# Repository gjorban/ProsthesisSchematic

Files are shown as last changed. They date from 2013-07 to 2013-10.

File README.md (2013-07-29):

Copyright (C) 2012 Gerald Orban

Permission is hereby granted, free of charge, to any person obtaining
a copy of this software and associated documentation files (the
"Software"), to deal in the Software without restriction, including
without limitation the rights to use, copy, modify, merge, publish,
distribute, sublicense, and/or sell copies of the Software, and to
permit persons to whom the Software is furnished to do so, subject to
the following conditions:

The above copyright notice and this permission notice shall be
included in all copies or substantial portions of the Software.

THE SOFTWARE IS PROVIDED "AS IS", WITHOUT WARRANTY OF ANY KIND,
EXPRESS OR IMPLIED, INCLUDING BUT NOT LIMITED TO THE WARRANTIES OF
MERCHANTABILITY, FITNESS FOR A PARTICULAR PURPOSE AND
NONINFRINGEMENT. IN NO EVENT SHALL GERALD ORBAN BE LIABLE FOR ANY
CLAIM, DAMAGES OR OTHER LIABILITY, WHETHER IN AN ACTION OF CONTRACT,
TORT OR OTHERWISE, ARISING FROM, OUT OF OR IN CONNECTION WITH THE
SOFTWARE OR THE USE OR OTHER DEALINGS IN THE SOFTWARE.

Except as contained in this notice, the name of Gerald Orban shall
not be used in advertising or otherwise to promote the sale, use or
other dealings in this Software without prior written authorization
from Gerald Orban.

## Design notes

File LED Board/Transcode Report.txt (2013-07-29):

   ---- Transcoding 'C:\Users\Gbot\Desktop\eatART LED Board\i2clight manual route.GBS' ----   Fri Jun 21 15:23:17 2013

D10   --> D100
D11   --> D101
D12   --> D102
D13   --> D103
D14   --> D104
D15   --> D105
D16   --> D106
D17   --> D107
-----------------------------------------------------------------

   ---- Transcoding 'C:\Users\Gbot\Desktop\eatART LED Board\i2clight manual route.GTL' ----   Fri Jun 21 15:23:17 2013

D10   --> D108
D11   --> D109
D12   --> D110
D13   --> D111
D14   --> D112
D15   --> D113
D16   --> D114
D17   --> D115
D18   --> D116
D19   --> D117
D20   --> D118
-----------------------------------------------------------------

   ---- Transcoding 'C:\Users\Gbot\Desktop\eatART LED Board\i2clight manual route.GTO' ----   Fri Jun 21 15:23:17 2013

D10   --> D119
D11   --> D120
D12   --> D121
D13   --> D122
D14   --> D123
D15   --> D124
D16   --> D125
D17   --> D126
D18   --> D127
D19   --> D128
D20   --> D129
D21   --> D130
D22   --> D131
D23   --> D132
D24   --> D133
D25   --> D134
D26   --> D135
D100  --> D136
D101  --> D137
D102  --> D138
D103  --> D139
-----------------------------------------------------------------

   ---- Transcoding 'C:\Users\Gbot\Desktop\eatART LED Board\i2clight manual route.GTS' ----   Fri Jun 21 15:23:17 2013

D10   --> D140
D11   --> D141
D12   --> D142
D13   --> D143
D14   --> D144
D15   --> D145
D16   --> D146
D17   --> D147
D18   --> D148
D19   --> D149
D20   --> D150
D21   --> D151
-----------------------------------------------------------------

   ---- Transcoding 'C:\Users\Gbot\Desktop\eatART LED Board\i2clight manual route.GBS' ----   Fri Jun 21 15:51:15 2013

D10   --> D100
D11   --> D101
D12   --> D102
D13   --> D103
D14   --> D104
D15   --> D105
D16   --> D106
D17   --> D107
-----------------------------------------------------------------

   ---- Transcoding 'C:\Users\Gbot\Desktop\eatART LED Board\i2clight manual route.GTL' ----   Fri Jun 21 15:51:15 2013

D10   --> D108
D11   --> D109
D12   --> D110
D13   --> D111
D14   --> D112
D15   --> D113
D16   --> D114
D17   --> D115
D18   --> D116
D19   --> D117
D20   --> D118
-----------------------------------------------------------------

   ---- Transcoding 'C:\Users\Gbot\Desktop\eatART LED Board\i2clight manual route.GTO' ----   Fri Jun 21 15:51:15 2013

D10   --> D119
D11   --> D120
D12   --> D121
D13   --> D122
D14   --> D123
D15   --> D124
D16   --> D125
D17   --> D126
D18   --> D127
D19   --> D128
D20   --> D129
D21   --> D130
D22   --> D131
D23   --> D132
D24   --> D133
D25   --> D134
D26   --> D135
D100  --> D136
D101  --> D137
D102  --> D138
D103  --> D139
-----------------------------------------------------------------

   ---- Transcoding 'C:\Users\Gbot\Desktop\eatART LED Board\i2clight manual route.GTS' ----   Fri Jun 21 15:51:15 2013

D10   --> D140
D11   --> D141
D12   --> D142
D13   --> D143
D14   --> D144
D15   --> D145
D16   --> D146
D17   --> D147
D18   --> D148
D19   --> D149
D20   --> D150
D21   --> D151
-----------------------------------------------------------------

   ---- Transcoding 'C:\Users\Gbot\Dropbox\2012 Electric Power Pack Control System\Schematics and Design Docs\Prosthesis LED Board\i2clight manual route.GBS' ----   Mon Jun 24 22:08:54 2013

D10   --> D100
D11   --> D101
D12   --> D102
D13   --> D103
D14   --> D104
D15   --> D105
D16   --> D106
D17   --> D107
-----------------------------------------------------------------

   ---- Transcoding 'C:\Users\Gbot\Dropbox\2012 Electric Power Pack Control System\Schematics and Design Docs\Prosthesis LED Board\i2clight manual route.GTL' ----   Mon Jun 24 22:08:54 2013

D10   --> D108
D11   --> D109
D12   --> D110
D13   --> D111
D14   --> D112
D15   --> D113
D16   --> D114
D17   --> D115
D18   --> D116
D19   --> D117
D20   --> D118
-----------------------------------------------------------------

   ---- Transcoding 'C:\Users\Gbot\Dropbox\2012 Electric Power Pack Control System\Schematics and Design Docs\Prosthesis LED Board\i2clight manual route.GTO' ----   Mon Jun 24 22:08:54 2013

D10   --> D119
D11   --> D120
D12   --> D121
D13   --> D122
D14   --> D123
D15   --> D124
D16   --> D125
D17   --> D126
D18   --> D127
D19   --> D128
D20   --> D129
D21   --> D130
D22   --> D131
D23   --> D132
D24   --> D133
D25   --> D134
D26   --> D135
D100  --> D136
D101  --> D137
D102  --> D138
D103  --> D139
-----------------------------------------------------------------

   ---- Transcoding 'C:\Users\Gbot\Dropbox\2012 Electric Power Pack Control System\Schematics and Design Docs\Prosthesis LED Board\i2clight manual route.GTS' ----   Mon Jun 24 22:08:54 2013

D10   --> D140
D11   --> D141
D12   --> D142
D13   --> D143
D14   --> D144
D15   --> D145
D16   --> D146
D17   --> D147
D18   --> D148
D19   --> D149
D20   --> D150
D21   --> D151
-----------------------------------------------------------------

   ---- Transcoding 'C:\Users\Gbot\Dropbox\2012 Electric Power Pack Control System\Schematics and Design Docs\Prosthesis LED Board\i2clight manual route.GBS' ----   Tue Jun 25 16:55:16 2013

D10   --> D100
D11   --> D101
D12   --> D102
D13   --> D103
D14   --> D104
D15   --> D105
D16   --> D106
D17   --> D107
-----------------------------------------------------------------

   ---- Transcoding 'C:\Users\Gbot\Dropbox\2012 Electric Power Pack Control System\Schematics and Design Docs\Prosthesis LED Board\i2clight manual route.GTL' ----   Tue Jun 25 16:55:16 2013

D10   --> D108
D11   --> D109
D12   --> D110
D13   --> D111
D14   --> D112
D15   --> D113
D16   --> D114
D17   --> D115
D18   --> D116
D19   --> D117
D20   --> D118
-----------------------------------------------------------------

   ---- Transcoding 'C:\Users\Gbot\Dropbox\2012 Electric Power Pack Control System\Schematics and Design Docs\Prosthesis LED Board\i2clight manual route.GTO' ----   Tue Jun 25 16:55:16 2013

D10   --> D119
D11   --> D120
D12   --> D121
D13   --> D122
D14   --> D123
D15   --> D124
D16   --> D125
D17   --> D126
D18   --> D127
D19   --> D128
D20   --> D129
D21   --> D130
D22   --> D131
D23   --> D132
D24   --> D133
D25   --> D134
D26   --> D135
D27   --> D136
D100  --> D137
D101  --> D138
D102  --> D139
D103  --> D140
-----------------------------------------------------------------

   ---- Transcoding 'C:\Users\Gbot\Dropbox\2012 Electric Power Pack Control System\Schematics and Design Docs\Prosthesis LED Board\i2clight manual route.GTS' ----   Tue Jun 25 16:55:16 2013

D10   --> D141
D11   --> D142
D12   --> D143
D13   --> D144
D14   --> D145
D15   --> D146
D16   --> D147
D17   --> D148
D18   --> D149
D19   --> D150
D20   --> D151
D21   --> D152
D22   --> D153
-----------------------------------------------------------------

   ---- Transcoding 'C:\Users\Gbot\Dropbox\2012 Electric Power Pack Control System\Schematics and Design Docs\Prosthesis LED Board\i2clight manual route.GBS' ----   Tue Jun 25 18:13:10 2013

D10   --> D100
D11   --> D101
D12   --> D102
D13   --> D103
D14   --> D104
D15   --> D105
D16   --> D106
D17   --> D107
-----------------------------------------------------------------

   ---- Transcoding 'C:\Users\Gbot\Dropbox\2012 Electric Power Pack Control System\Schematics and Design Docs\Prosthesis LED Board\i2clight manual route.GTL' ----   Tue Jun 25 18:13:10 2013

D10   --> D108
D11   --> D109
D12   --> D110
D13   --> D111
D14   --> D112
D15   --> D113
D16   --> D114
D17   --> D115
D18   --> D116
D19   --> D117
D20   --> D118
-----------------------------------------------------------------

   ---- Transcoding 'C:\Users\Gbot\Dropbox\2012 Electric Power Pack Control System\Schematics and Design Docs\Prosthesis LED Board\i2clight manual route.GTO' ----   Tue Jun 25 18:13:10 2013

D10   --> D119
D11   --> D120
D12   --> D121
D13   --> D122
D14   --> D123
D15   --> D124
D16   --> D125
D17   --> D126
D18   --> D127
D19   --> D128
D20   --> D129
D21   --> D130
D22   --> D131
D23   --> D132
D24   --> D133
D25   --> D134
D26   --> D135
D27   --> D136
D100  --> D137
D101  --> D138
D102  --> D139
D103  --> D140
-----------------------------------------------------------------

   ---- Transcoding 'C:\Users\Gbot\Dropbox\2012 Electric Power Pack Control System\Schematics and Design Docs\Prosthesis LED Board\i2clight manual route.GTS' ----   Tue Jun 25 18:13:10 2013

D10   --> D141
D11   --> D142
D12   --> D143
D13   --> D144
D14   --> D145
D15   --> D146
D16   --> D147
D17   --> D148
D18   --> D149
D19   --> D150
D20   --> D151
D21   --> D152
D22   --> D153
-----------------------------------------------------------------

   ---- Transcoding 'C:\Users\Gbot\Dropbox\2012 Electric Power Pack Control System\Schematics and Design Docs\Prosthesis LED Board\i2clight manual route.GBS' ----   Wed Jun 26 16:44:21 2013

D10   --> D100
D11   --> D101
D12   --> D102
D13   --> D103
D14   --> D104
D15   --> D105
D16   --> D106
D17   --> D107
-----------------------------------------------------------------

   ---- Transcoding 'C:\Users\Gbot\Dropbox\2012 Electric Power Pack Control System\Schematics and Design Docs\Prosthesis LED Board\i2clight manual route.GTL' ----   Wed Jun 26 16:44:21 2013

D10   --> D108
D11   --> D109
D12   --> D110
D13   --> D111
D14   --> D112
D15   --> D113
D16   --> D114
D17   --> D115
D18   --> D116
D19   --> D117
D20   --> D118
-----------------------------------------------------------------

   ---- Transcoding 'C:\Users\Gbot\Dropbox\2012 Electric Power Pack Control System\Schematics and Design Docs\Prosthesis LED Board\i2clight manual route.GTO' ----   Wed Jun 26 16:44:21 2013

D10   --> D119
D11   --> D120
D12   --> D121
D13   --> D122
D14   --> D123
D15   --> D124
D16   --> D125
D17   --> D126
D18   --> D127
D19   --> D128
D20   --> D129
D21   --> D130
D22   --> D131
D23   --> D132
D24   --> D133
D25   --> D134
D26   --> D135
D27   --> D136
D100  --> D137
D101  --> D138
D102  --> D139
D103  --> D140
-----------------------------------------------------------------

   ---- Transcoding 'C:\Users\Gbot\Dropbox\2012 Electric Power Pack Control System\Schematics and Design Docs\Prosthesis LED Board\i2clight manual route.GTS' ----   Wed Jun 26 16:44:21 2013

D10   --> D141
D11   --> D142
D12   --> D143
D13   --> D144
D14   --> D145
D15   --> D146
D16   --> D147
D17   --> D148
D18   --> D149
D19   --> D150
D20   --> D151
D21   --> D152
D22   --> D153
-----------------------------------------------------------------

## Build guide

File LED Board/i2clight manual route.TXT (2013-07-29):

%
M48
M72
T01C0.0276
T02C0.0300
T03C0.0400
T04C0.0440
T05C0.0470
T06C0.1300
%
T01
X5600Y5100
X5600Y6100
X34600Y11600
X35600Y11600
T02
X31975Y11975
X30475Y11975
X28975Y11975
X25975Y11975
X24475Y11975
X22975Y11975
X21975Y10975
X22350Y10350
X24350Y9850
X26350Y9350
X26850Y9725
X28350Y8850
X30350Y8350
X30350Y7100
X28350Y7100
X26350Y7100
X26100Y6350
X26975Y5350
X25100Y5350
X24100Y6350
X24350Y7100
X22350Y7100
X21975Y6350
X21350Y5350
X20100Y5975
X18225Y5100
X17600Y5475
X19225Y4725
X23100Y5350
X20100Y7100
X17475Y6725
X14600Y7850
X14225Y6725
X10850Y4725
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

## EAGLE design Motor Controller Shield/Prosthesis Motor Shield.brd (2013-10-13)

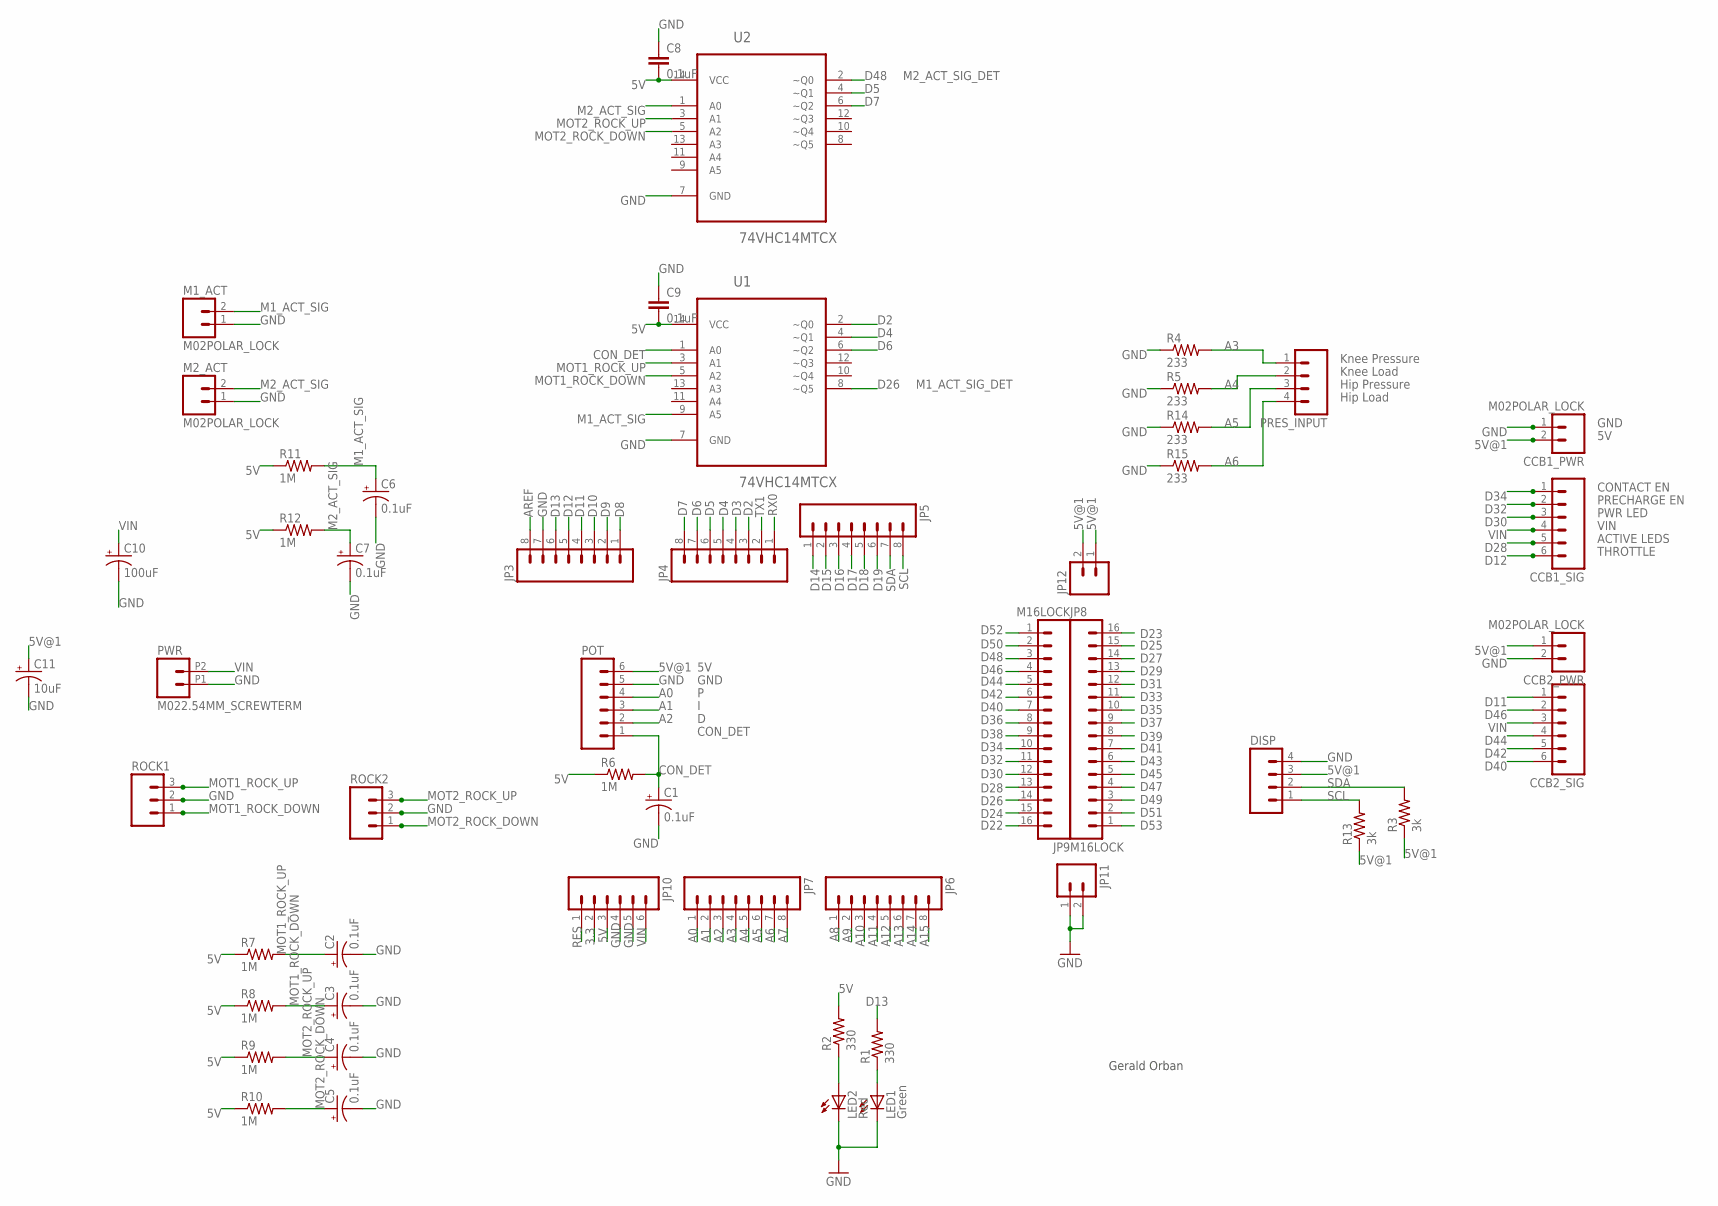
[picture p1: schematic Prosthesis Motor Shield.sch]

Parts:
C1, C2, C3, C4, C5, C6, C7: 0.1uF; EIA3216
C8, C9: 0.1uF; 0603-CAP
C10: 100uF; CPOL-RADIAL-100UF-25V
C11: 10uF; CPOL-RADIAL-10UF-25V
CCB1_PWR, CCB2_PWR: M02POLAR_LOCK; MOLEX-1X2_LOCK
CCB1_SIG, CCB2_SIG: M06POLAR_LOCK; MOLEX-1X6_LOCK
DISP: M04POLAR_LOCK; MOLEX-1X4_LOCK
JP3, JP4, JP5, JP6, JP7: M08LOCK; 1X08_LOCK
JP8, JP9: M16LOCK; 1X16_LOCK
JP10: M06LOCK; 1X06_LOCK
JP11, JP12: M02LOCK; 1X02_LOCK
LED1: Green; LED-1206
LED2: Red; LED-1206
M1_ACT, M2_ACT: M02POLAR_LOCK; MOLEX-1X2_LOCK
POT: M06POLAR_LOCK; MOLEX-1X6_LOCK
PRES_INPUT: M04POLAR_LOCK; MOLEX-1X4_LOCK
PWR: M022.54MM_SCREWTERM; 1X02_2.54_SCREWTERM
R1, R2: 330; 0805
R3, R13: 3k; 0603-RES
R4, R5, R14, R15: 233; AXIAL-0.4
R6, R7, R8, R9, R10, R11, R12: 1M; 0603-RES
ROCK1, ROCK2: M03POLAR_LOCK; MOLEX-1X3_LOCK
U1, U2: 74VHC14MTCX; SOP65P640X120-14N

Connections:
3.3: JP10.2
5V: C8.2, C9.2, JP10.3, R2.2, R6.1, R7.1, R8.1, R9.1, R10.1, R11.1, R12.1, U1.14 (VCC), U2.14 (VCC)
5V@1: C11.1 (+), CCB1_PWR.2, CCB2_PWR.1, DISP.3, JP12.1, JP12.2, POT.6, R3.1, R13.1
A0: JP7.1, POT.4
A1: JP7.2, POT.3
A2: JP7.3, POT.2
A3: JP7.4, PRES_INPUT.1, R4.P$2 (2)
A4: JP7.5, PRES_INPUT.2, R5.P$2 (2)
A5: JP7.6, PRES_INPUT.3, R14.P$2 (2)
A6: JP7.7, PRES_INPUT.4, R15.P$2 (2)
A7: JP7.8
A8: JP6.1
A9: JP6.2
A10: JP6.3
A11: JP6.4
A12: JP6.5
A13: JP6.6
A14: JP6.7
A15: JP6.8
AREF: JP3.8
CON_DET: C1.A (+), POT.1, R6.2, U1.1 (A0)
D2: JP4.3, U1.2 (~Q0)
D3: JP4.4
D4: JP4.5, U1.4 (~Q1)
D5: JP4.6, U2.4 (~Q1)
D6: JP4.7, U1.6 (~Q2)
D7: JP4.8, U2.6 (~Q2)
D8: JP3.1
D9: JP3.2
D10: JP3.3
D11: CCB2_SIG.1, JP3.4
D12: CCB1_SIG.6, JP3.5
D13: JP3.6, R1.2
D14: JP5.1
D15: JP5.2
D16: JP5.3
D17: JP5.4
D18: JP5.5
D19: JP5.6
D22: JP9.16
D23: JP8.16
D24: JP9.15
D25: JP8.15
D26: JP9.14, U1.8 (~Q5)
D27: JP8.14
D28: CCB1_SIG.5, JP9.13
D29: JP8.13
D30: CCB1_SIG.3, JP9.12
D31: JP8.12
D32: CCB1_SIG.2, JP9.11
D33: JP8.11
D34: CCB1_SIG.1, JP9.10
D35: JP8.10
D36: JP9.9
D37: JP8.9
D38: JP9.8
D39: JP8.8
D40: CCB2_SIG.6, JP9.7
D41: JP8.7
D42: CCB2_SIG.5, JP9.6
D43: JP8.6
D44: CCB2_SIG.4, JP9.5
D45: JP8.5
D46: CCB2_SIG.2, JP9.4
D47: JP8.4
D48: JP9.3, U2.2 (~Q0)
D49: JP8.3
D50: JP9.2
D51: JP8.2
D52: JP9.1
D53: JP8.1
GND: C1.C (-), C2.C (-), C3.C (-), C4.C (-), C5.C (-), C6.C (-), C7.C (-), C8.1, C9.1, C10.2 (-), C11.2 (-), CCB1_PWR.1, CCB2_PWR.2, DISP.4, JP3.7, JP10.4, JP10.5, JP11.1, JP11.2, LED1.C, LED2.C, M1_ACT.1, M2_ACT.1, POT.5, PWR.P1 (1), R4.P$1 (1), R5.P$1 (1), R14.P$1 (1), R15.P$1 (1), ROCK1.2, ROCK2.2, U1.7 (GND), U2.7 (GND)
M1_ACT_SIG: C6.A (+), M1_ACT.2, R11.2, U1.9 (A5)
M2_ACT_SIG: C7.A (+), M2_ACT.2, R12.2, U2.1 (A0)
MOT1_ROCK_DOWN: C3.A (+), R8.2, ROCK1.1, U1.5 (A2)
MOT1_ROCK_UP: C2.A (+), R7.2, ROCK1.3, U1.3 (A1)
MOT2_ROCK_DOWN: C5.A (+), R10.2, ROCK2.1, U2.5 (A2)
MOT2_ROCK_UP: C4.A (+), R9.2, ROCK2.3, U2.3 (A1)
unnamed: LED2.A, R2.1
unnamed: LED1.A, R1.1
RES: JP10.1
RX0: JP4.1
SCL: DISP.1, JP5.8, R13.2
SDA: DISP.2, JP5.7, R3.2
TX1: JP4.2
VIN: C10.1 (+), CCB1_SIG.4, CCB2_SIG.3, JP10.6, PWR.P2 (2)

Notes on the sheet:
Gerald Orban
THROTTLE
ACTIVE LEDS
VIN
PWR LED
PRECHARGE EN
CONTACT EN
GND
CON_DET
Knee Pressure
Knee Load
Hip Pressure
Hip Load
M2_ACT_SIG_DET
M1_ACT_SIG_DET

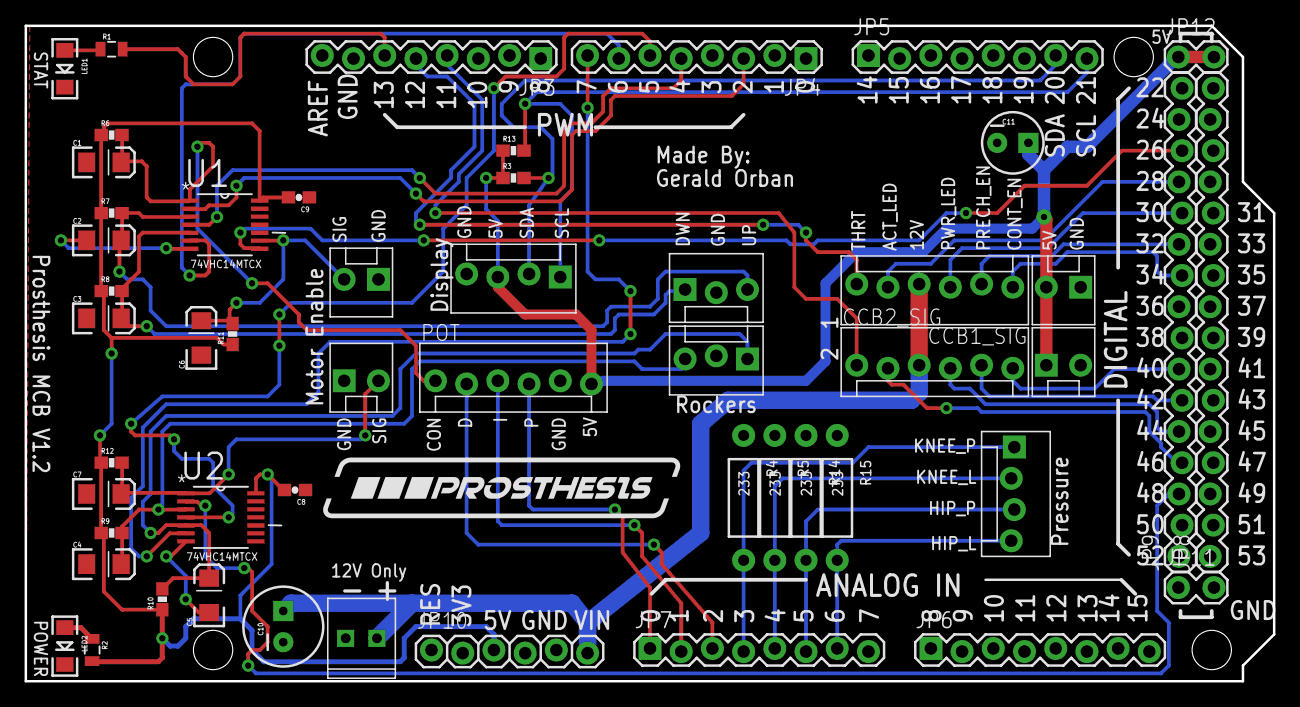
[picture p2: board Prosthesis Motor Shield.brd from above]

Board: 2 copper layers, 101.6 x 53.3 mm, 53 parts (0 on the bottom side), 40 nets.

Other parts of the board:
U$1: PROS_LOGO

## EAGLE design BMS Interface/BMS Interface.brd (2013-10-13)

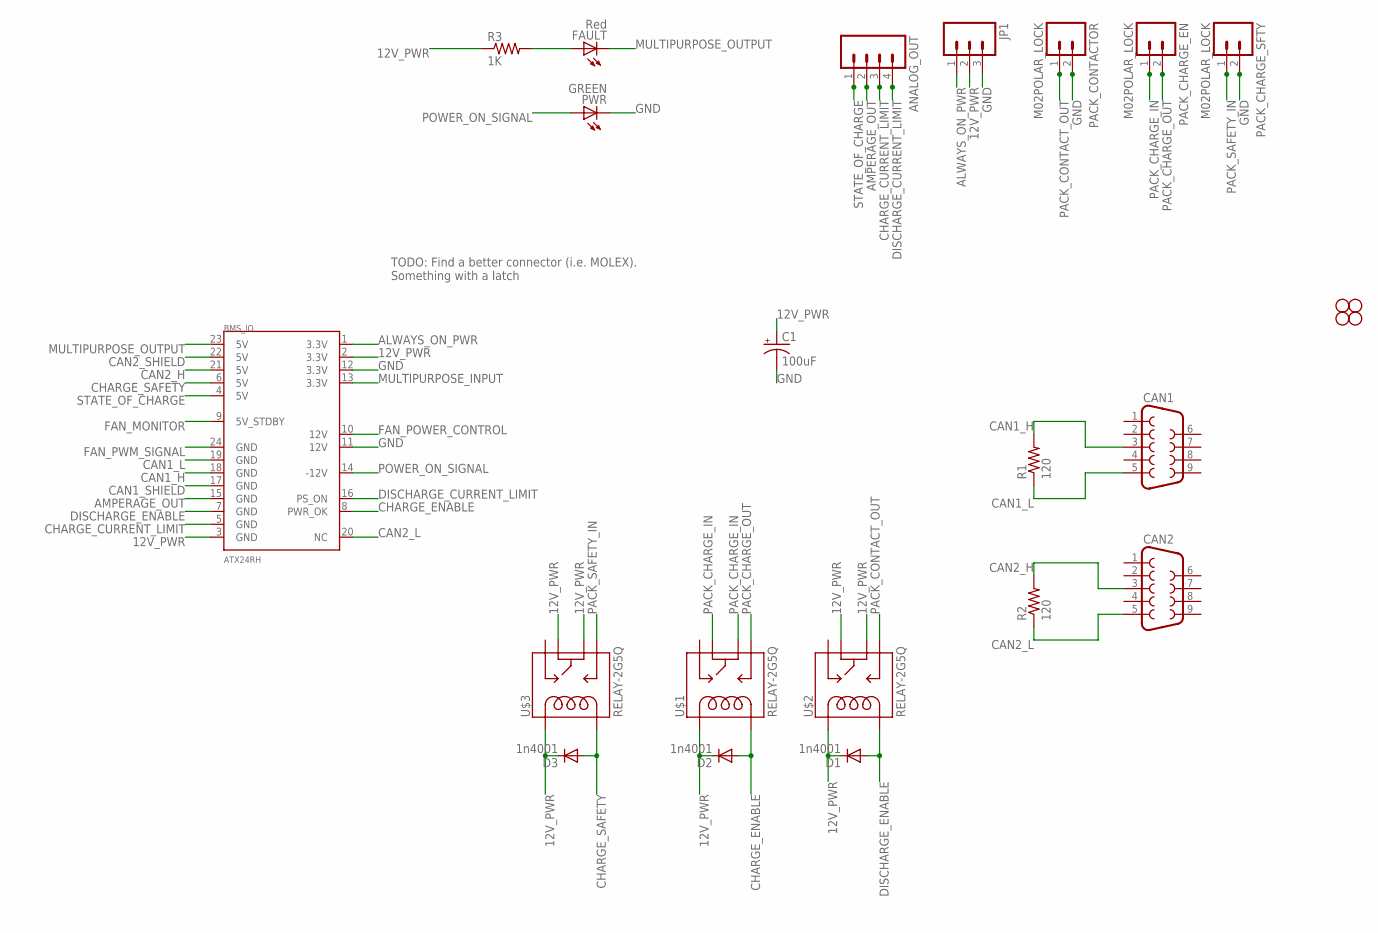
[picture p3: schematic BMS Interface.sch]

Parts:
ANALOG_OUT: M04POLAR_LOCK; MOLEX-1X4_LOCK
BMS_IO: ATX24RH; ATX24_RIGHT_ANGLE
C1: 100uF; CPOL-RADIAL-100UF-25V
CAN1, CAN2: DB9FEMALE; DB9
D1, D2, D3: 1n4001; SMA-DIODE
FAULT: Red; LED5MM
JP1: M03SCREW; SCREWTERMINAL-3.5MM-3
PACK_CHARGE_EN: M02POLAR_LOCK; MOLEX-1X2_LOCK
PACK_CHARGE_SFTY: M02POLAR_LOCK; MOLEX-1X2_LOCK
PACK_CONTACTOR: M02POLAR_LOCK; MOLEX-1X2_LOCK
PWR: GREEN; LED5MM
R1, R2: 120; 0603-RES
R3: 1K; 0805
STANDOFF1, STANDOFF2, STANDOFF3, STANDOFF4: STAND-OFF
U$1, U$2, U$3: RELAY-2G5Q; RELAY-G5V

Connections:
12V_PWR: BMS_IO.2 (3.3V), BMS_IO.3 (GND), C1.1 (+), D1.C, D2.C, D3.C, JP1.2, R3.1, U$1.2, U$2.2, U$2.5, U$2.6, U$3.2, U$3.5, U$3.6
ALWAYS_ON_PWR: BMS_IO.1 (3.3V), JP1.1
AMPERAGE_OUT: ANALOG_OUT.2, BMS_IO.15 (GND)
CAN1_H: BMS_IO.18 (GND), CAN1.3, R1.2
CAN1_L: BMS_IO.19 (GND), CAN1.5, R1.1
CAN1_SHIELD: BMS_IO.17 (GND)
CAN2_H: BMS_IO.21 (5V), CAN2.3, R2.2
CAN2_L: BMS_IO.20 (NC), CAN2.5, R2.1
CAN2_SHIELD: BMS_IO.22 (5V)
CHARGE_CURRENT_LIMIT: ANALOG_OUT.3, BMS_IO.5 (GND)
CHARGE_ENABLE: BMS_IO.8 (PWR_OK), D2.A, U$1.9
CHARGE_SAFETY: BMS_IO.6 (5V), D3.A, U$3.9
DISCHARGE_CURRENT_LIMIT: ANALOG_OUT.4, BMS_IO.16 (PS_ON)
DISCHARGE_ENABLE: BMS_IO.7 (GND), D1.A, U$2.9
FAN_MONITOR: BMS_IO.9 (5V_STDBY)
FAN_POWER_CONTROL: BMS_IO.10 (12V)
FAN_PWM_SIGNAL: BMS_IO.24 (GND)
GND: BMS_IO.11 (12V), BMS_IO.12 (3.3V), C1.2 (-), JP1.3, PACK_CHARGE_SFTY.2, PACK_CONTACTOR.2, PWR.K (C)
MULTIPURPOSE_INPUT: BMS_IO.13 (3.3V)
MULTIPURPOSE_OUTPUT: BMS_IO.23 (5V), FAULT.K (C)
unnamed: FAULT.A, R3.2
PACK_CHARGE_IN: PACK_CHARGE_EN.1, U$1.5, U$1.6
PACK_CHARGE_OUT: PACK_CHARGE_EN.2, U$1.10
PACK_CONTACT_OUT: PACK_CONTACTOR.1, U$2.10
PACK_SAFETY_IN: PACK_CHARGE_SFTY.1, U$3.10
POWER_ON_SIGNAL: BMS_IO.14 (-12V), PWR.A
STATE_OF_CHARGE: ANALOG_OUT.1, BMS_IO.4 (5V)

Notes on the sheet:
TODO: Find a better connector (i.e. MOLEX). Something with a latch

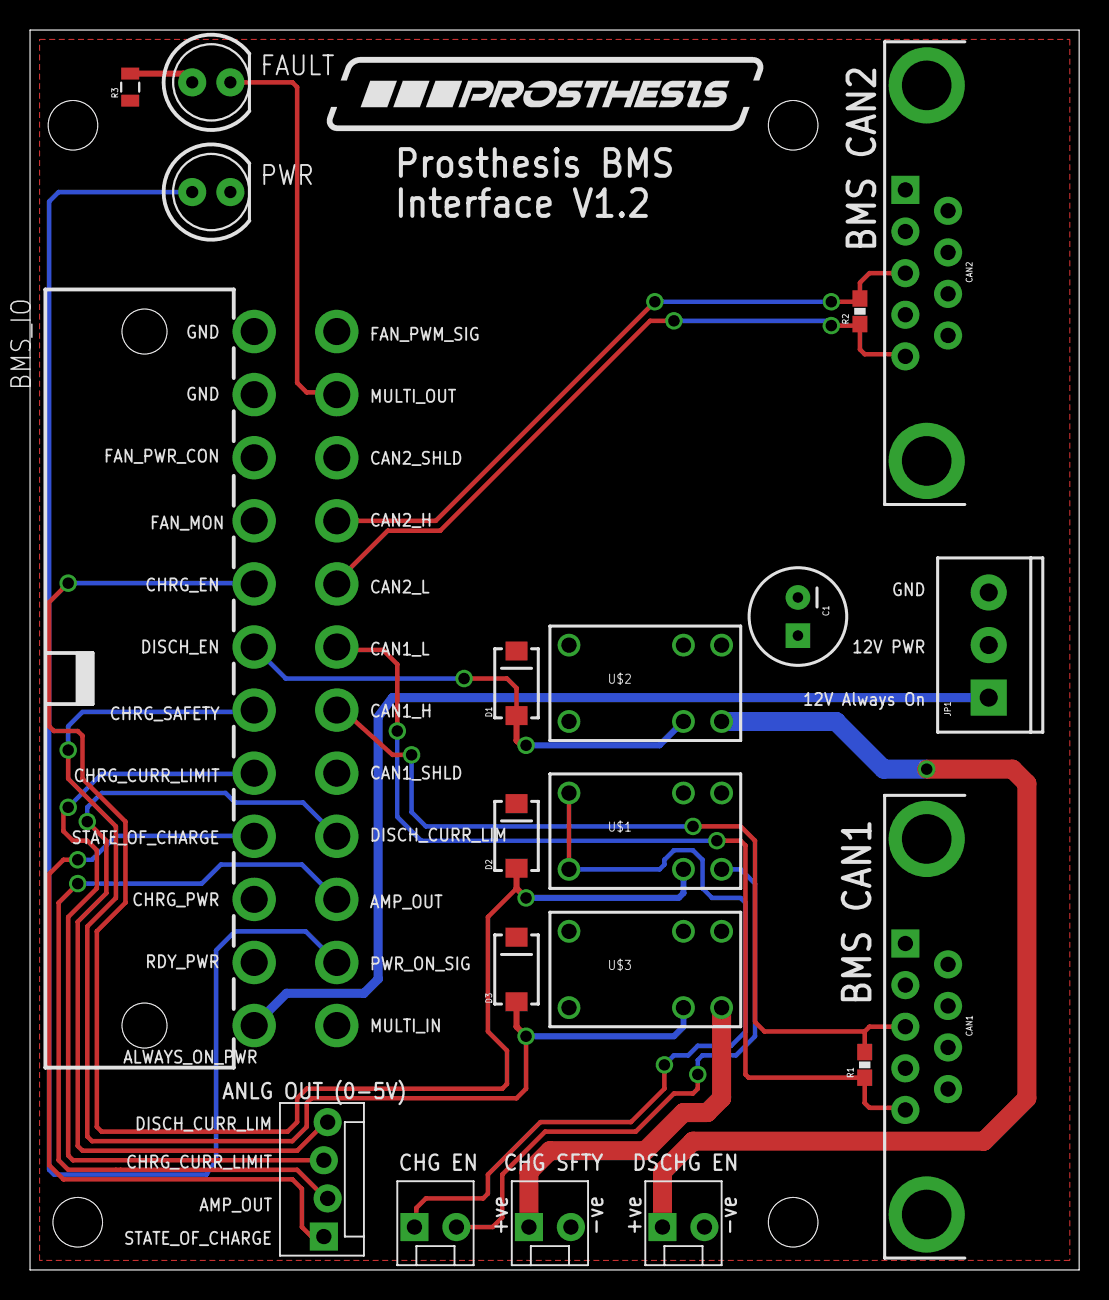
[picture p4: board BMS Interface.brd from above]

Board: 2 copper layers, 69.8 x 82.5 mm, 25 parts (0 on the bottom side), 21 nets.

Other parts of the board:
U$4: PROS_LOGO

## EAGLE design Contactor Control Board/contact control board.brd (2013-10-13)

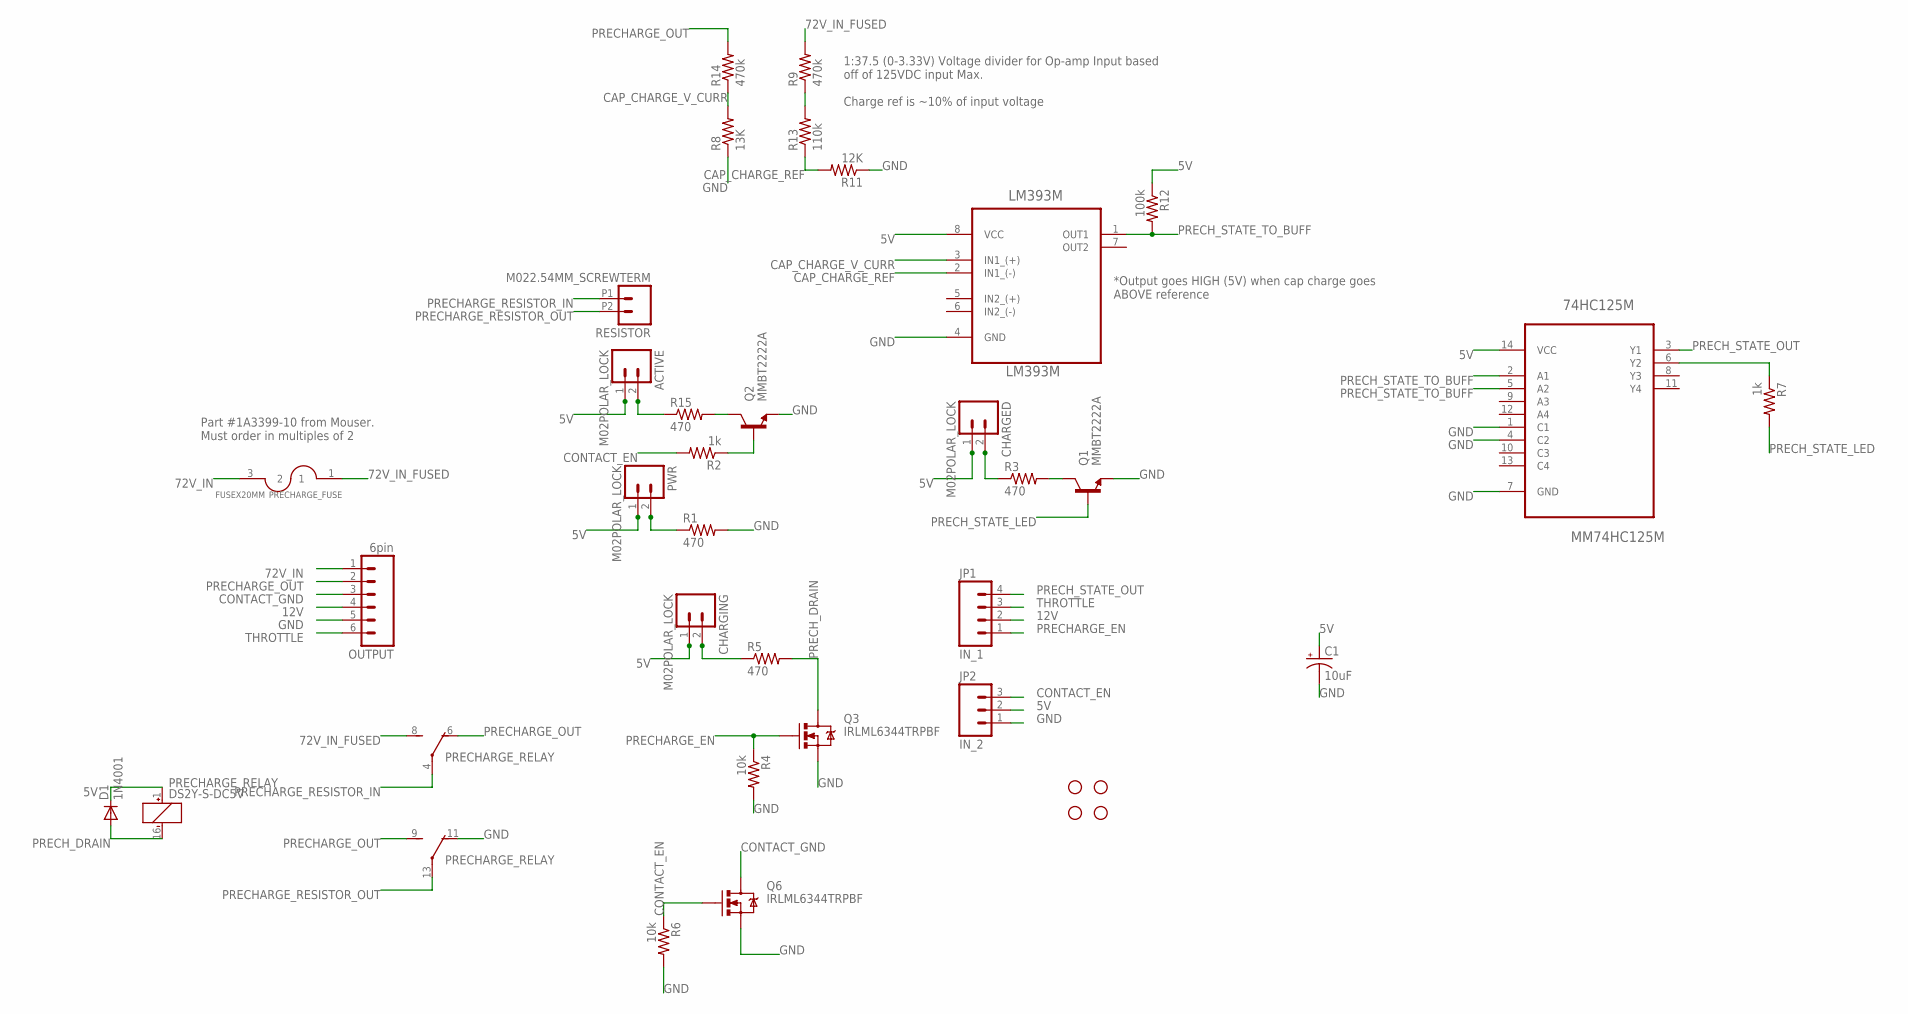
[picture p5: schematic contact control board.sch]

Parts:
74HC125M: MM74HC125M; SOIC127P600X175-14N
ACTIVE: M02POLAR_LOCK; MOLEX-1X2_LOCK
C1: 10uF; CPOL-RADIAL-10UF-25V
CHARGED: M02POLAR_LOCK; MOLEX-1X2_LOCK
CHARGING: M02POLAR_LOCK; MOLEX-1X2_LOCK
D1: 1N4001; DIODE-1N4001
JP1: IN_1; MOLEX-1X4_LOCK
JP2: IN_2; MOLEX-1X3_LOCK
LM393M: LM393M; SOIC127P600X180-8N
OUTPUT: 6pin; SCREWTERMINAL-3.5MM-6
PRECHARGE_FUSE: FUSEX20MM; FUSE_5MM
PRECHARGE_RELAY: DS2Y-S-DC5V; DS2Y
PWR: M02POLAR_LOCK; MOLEX-1X2_LOCK
Q1, Q2: MMBT2222A; SOT23
Q3, Q6: IRLML6344TRPBF; SOT23
R1, R3, R5, R15: 470; 0805
R2, R7: 1k; 0603-RES
R4, R6: 10k; 0603-RES
R8: 13K; 0805
R9, R14: 470k; 0805
R11: 12K; 0805
R12: 100k; 0603-RES
R13: 110k; 0805
RESISTOR: M022.54MM_SCREWTERM; 1X02_2.54_SCREWTERM
STANDOFF1, STANDOFF2, STANDOFF3, STANDOFF4: STAND-OFF

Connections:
5V: 74HC125M.14 (VCC), ACTIVE.1, C1.1 (+), CHARGED.1, CHARGING.1, D1.C, JP2.2, LM393M.8 (VCC), PRECHARGE_RELAY.1 (+), PWR.1, R12.1
12V: JP1.2, OUTPUT.4
72V_IN: OUTPUT.1, PRECHARGE_FUSE.3 (2)
72V_IN_FUSED: PRECHARGE_FUSE.1, PRECHARGE_RELAY.8 (S), R9.2
CAP_CHARGE_REF: LM393M.2 (IN1_(-)), R11.2, R13.1
CAP_CHARGE_V_CURR: LM393M.3 (IN1_(+)), R8.2, R14.1
CONTACT_EN: JP2.3, Q6.1 (G), R2.2, R6.1
CONTACT_GND: OUTPUT.3, Q6.3 (D)
GND: 74HC125M.1 (C1), 74HC125M.4 (C2), 74HC125M.7 (GND), C1.2 (-), JP2.1, LM393M.4 (GND), OUTPUT.5, PRECHARGE_RELAY.11 (O), Q1.2 (E), Q2.2 (E), Q3.2 (S), Q6.2 (S), R1.2, R4.2, R6.2, R8.1, R11.1
unnamed: Q2.3 (C), R15.2
unnamed: Q2.1 (B), R2.1
unnamed: R9.1, R13.2
unnamed: CHARGED.2, R3.1
unnamed: Q1.3 (C), R3.2
unnamed: 74HC125M.6 (Y2), R7.1
unnamed: CHARGING.2, R5.1
unnamed: ACTIVE.2, R15.1
unnamed: PWR.2, R1.1
PRECHARGE_EN: JP1.1, Q3.1 (G), R4.1
PRECHARGE_OUT: OUTPUT.2, PRECHARGE_RELAY.6 (O), PRECHARGE_RELAY.9 (S), R14.2
PRECHARGE_RESISTOR_IN: PRECHARGE_RELAY.4, RESISTOR.P1 (1)
PRECHARGE_RESISTOR_OUT: PRECHARGE_RELAY.13, RESISTOR.P2 (2)
PRECH_DRAIN: D1.A, PRECHARGE_RELAY.16 (-), Q3.3 (D), R5.2
PRECH_STATE_LED: Q1.1 (B), R7.2
PRECH_STATE_OUT: 74HC125M.3 (Y1), JP1.4
PRECH_STATE_TO_BUFF: 74HC125M.2 (A1), 74HC125M.5 (A2), LM393M.1 (OUT1), R12.2
THROTTLE: JP1.3, OUTPUT.6

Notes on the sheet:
1:37.5 (0-3.33V) Voltage divider for Op-amp Input based off of 125VDC input Max. Charge ref is ~10% of input voltage
*Output goes HIGH (5V) when cap charge goes ABOVE reference
Part #1A3399-10 from Mouser. Must order in multiples of 2

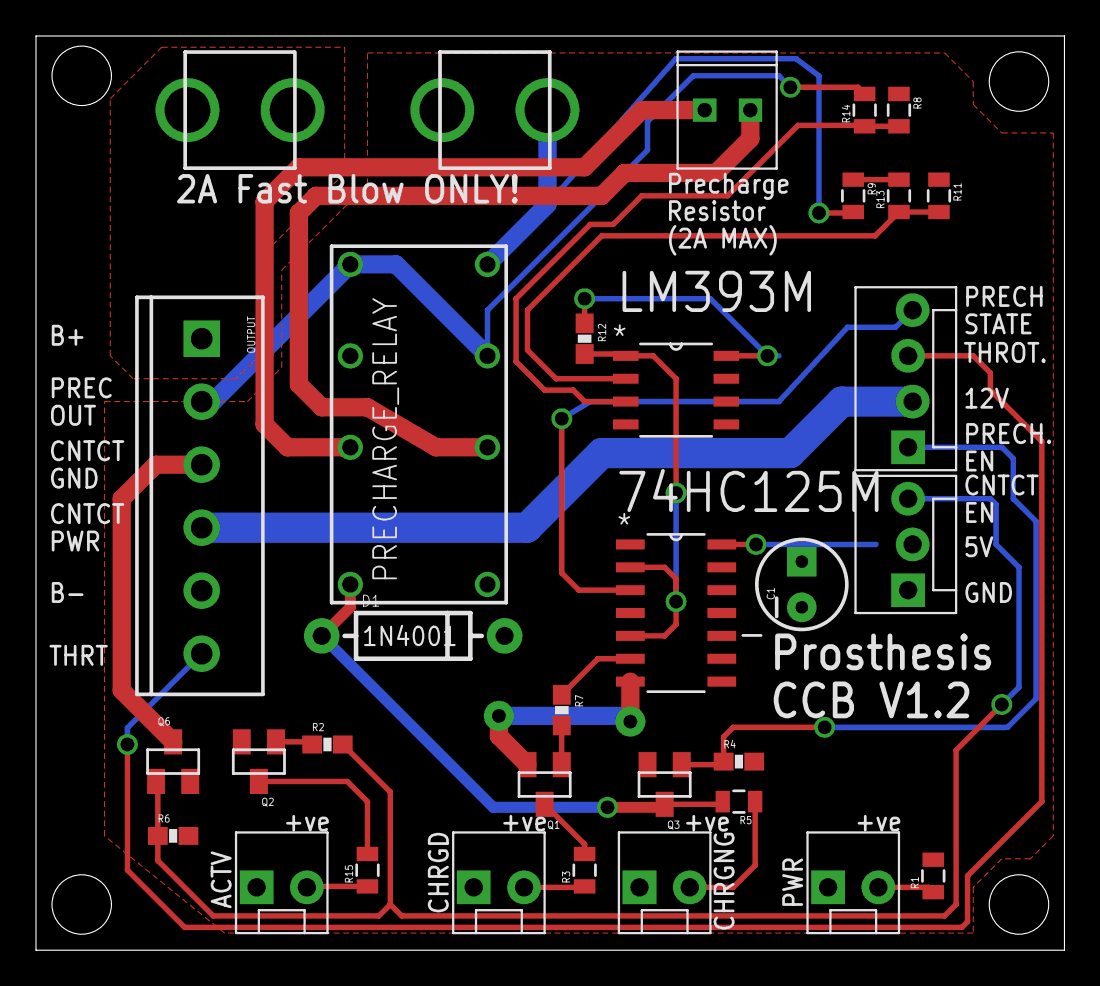
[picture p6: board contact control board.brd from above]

Board: 2 copper layers, 57.1 x 50.8 mm, 36 parts (0 on the bottom side), 27 nets.

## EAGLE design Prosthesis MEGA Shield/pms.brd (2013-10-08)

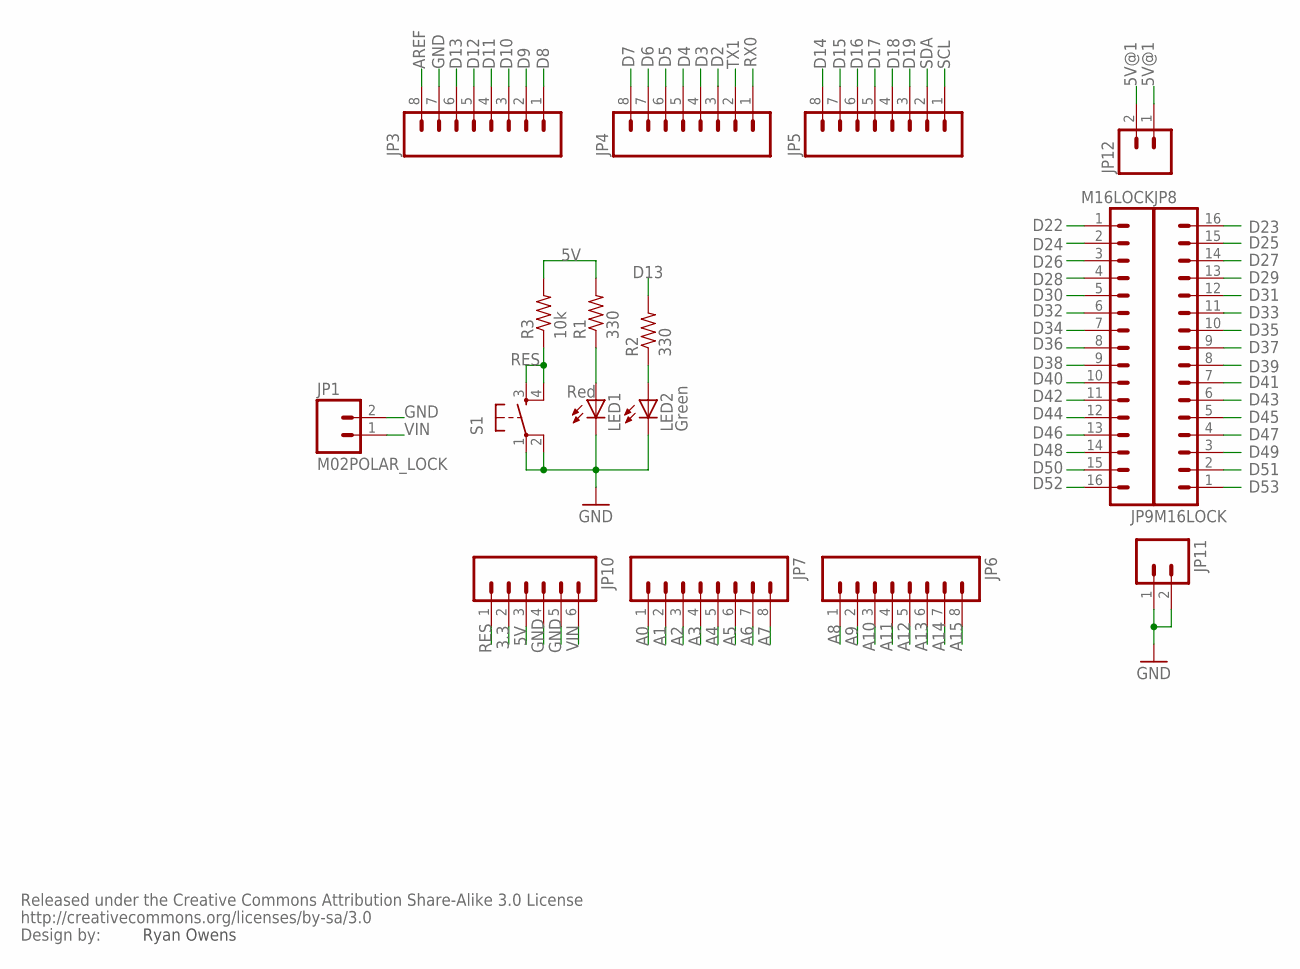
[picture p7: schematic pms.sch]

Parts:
JP1: M02POLAR_LOCK; MOLEX-1X2_LOCK
JP3, JP4, JP5, JP6, JP7: M08LOCK; 1X08_LOCK
JP8, JP9: M16LOCK; 1X16_LOCK
JP10: M06LOCK; 1X06_LOCK
JP11, JP12: M02LOCK; 1X02_LOCK
LED1: Red; LED5MM
LED2: Green; LED5MM
R1, R2: 330; AXIAL-0.3
R3: 10k; AXIAL-0.3
S1: TAC_SWITCHPTH; TACTILE-PTH
U$2: CREATIVE_COMMONS

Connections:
3.3: JP10.2
5V: JP10.3, R1.P$2 (2), R3.P$2 (2)
5V@1: JP12.1, JP12.2
A0: JP7.1
A1: JP7.2
A2: JP7.3
A3: JP7.4
A4: JP7.5
A5: JP7.6
A6: JP7.7
A7: JP7.8
A8: JP6.1
A9: JP6.2
A10: JP6.3
A11: JP6.4
A12: JP6.5
A13: JP6.6
A14: JP6.7
A15: JP6.8
AREF: JP3.8
D2: JP4.3
D3: JP4.4
D4: JP4.5
D5: JP4.6
D6: JP4.7
D7: JP4.8
D8: JP3.1
D9: JP3.2
D10: JP3.3
D11: JP3.4
D12: JP3.5
D13: JP3.6, R2.P$2 (2)
D14: JP5.8
D15: JP5.7
D16: JP5.6
D17: JP5.5
D18: JP5.4
D19: JP5.3
D22: JP9.1
D23: JP8.16
D24: JP9.2
D25: JP8.15
D26: JP9.3
D27: JP8.14
D28: JP9.4
D29: JP8.13
D30: JP9.5
D31: JP8.12
D32: JP9.6
D33: JP8.11
D34: JP9.7
D35: JP8.10
D36: JP9.8
D37: JP8.9
D38: JP9.9
D39: JP8.8
D40: JP9.10
D41: JP8.7
D42: JP9.11
D43: JP8.6
D44: JP9.12
D45: JP8.5
D46: JP9.13
D47: JP8.4
D48: JP9.14
D49: JP8.3
D50: JP9.15
D51: JP8.2
D52: JP9.16
D53: JP8.1
GND: JP1.2, JP3.7, JP10.4, JP10.5, JP11.1, JP11.2, LED1.K (C), LED2.K (C), S1.1, S1.2
unnamed: LED1.A, R1.P$1 (1)
unnamed: LED2.A, R2.P$1 (1)
RES: JP10.1, R3.P$1 (1), S1.3, S1.4
RX0: JP4.1
SCL: JP5.1
SDA: JP5.2
TX1: JP4.2
VIN: JP1.1, JP10.6

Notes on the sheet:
Ryan Owens

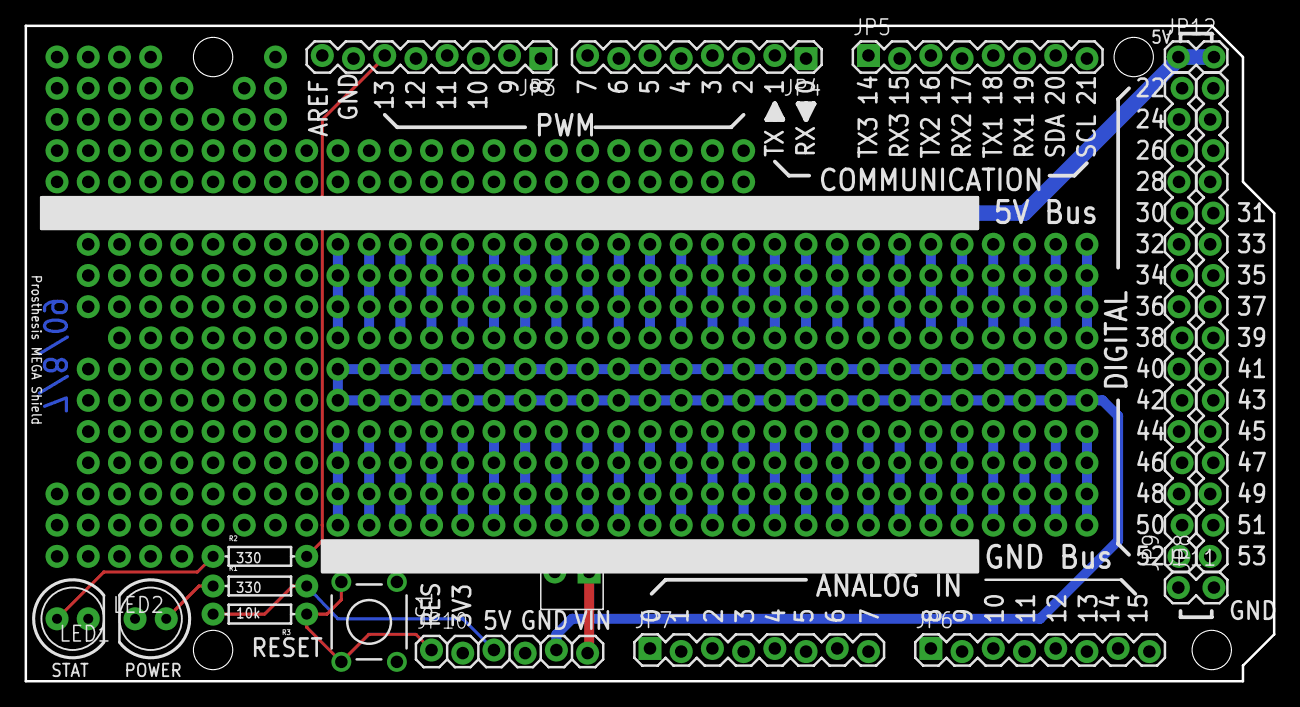
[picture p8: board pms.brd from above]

Board: 2 copper layers, 101.6 x 53.3 mm, 18 parts (0 on the bottom side), 8 nets.

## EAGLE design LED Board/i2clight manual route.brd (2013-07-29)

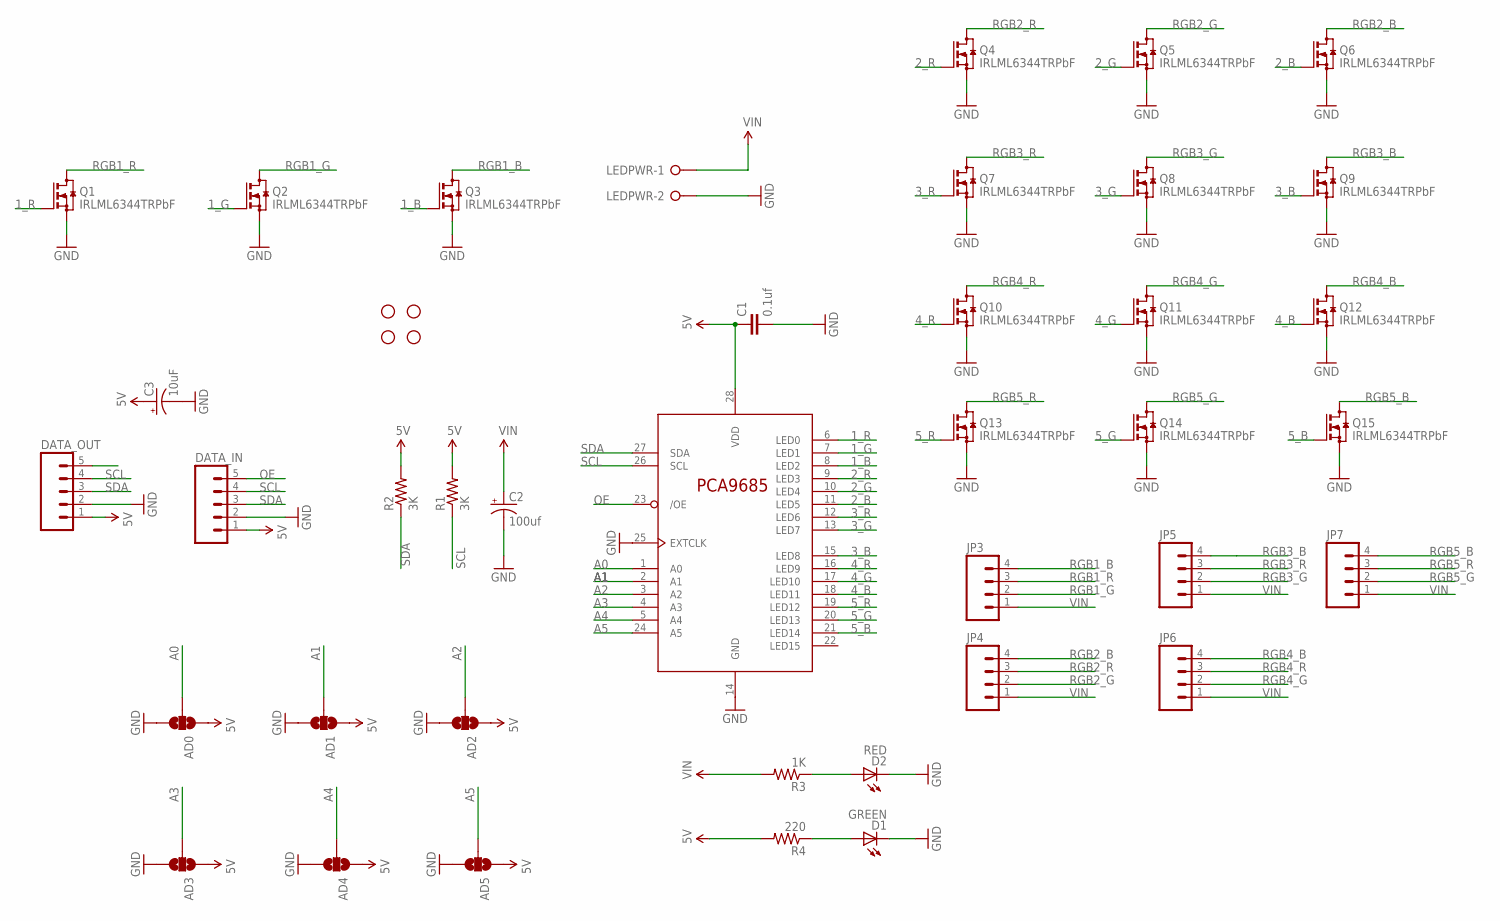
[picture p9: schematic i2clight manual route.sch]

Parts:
AD0, AD1, AD2, AD3, AD4, AD5: SOLDERJUMPER_2WAYT; SJ_2
C1: 0.1uf; 0805
C2: 100uf; CPOL-RADIAL-100UF-25V
C3: 10uF; CPOL-RADIAL-10UF-25V
D1: GREEN; LED-1206
D2: RED; LED-1206
DATA_IN: M05PTH_LONGPADS; 1X05_LONGPADS
DATA_OUT: M05PTH_LONGPADS; 1X05_LONGPADS
JP3, JP4, JP5, JP6, JP7: M04POLAR; MOLEX-1X4
LEDPWR: W237-02P; W237-132
PCA9685PW: PCA9685PW; TSSOP28
Q1, Q2, Q3, Q4, Q5, Q6, Q7, Q8, Q9, Q10, Q11, Q12, Q13, Q14, Q15: IRLML6344TRPbF; SOT23
R1, R2: 3K; 0805
R3: 1K; 0805
R4: 220; 0805
STANDOFF1, STANDOFF2, STANDOFF3, STANDOFF4: STAND-OFF

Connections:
1_B: PCA9685PW.8 (LED2), Q3.1 (G)
1_G: PCA9685PW.7 (LED1), Q2.1 (G)
1_R: PCA9685PW.6 (LED0), Q1.1 (G)
2_B: PCA9685PW.11 (LED5), Q6.1 (G)
2_G: PCA9685PW.10 (LED4), Q5.1 (G)
2_R: PCA9685PW.9 (LED3), Q4.1 (G)
3_B: PCA9685PW.15 (LED8), Q9.1 (G)
3_G: PCA9685PW.13 (LED7), Q8.1 (G)
3_R: PCA9685PW.12 (LED6), Q7.1 (G)
4_B: PCA9685PW.18 (LED11), Q12.1 (G)
4_G: PCA9685PW.17 (LED10), Q11.1 (G)
4_R: PCA9685PW.16 (LED9), Q10.1 (G)
5V: AD0.1, AD1.1, AD2.1, AD3.1, AD4.1, AD5.1, C1.1, C3.1 (+), DATA_IN.1, DATA_OUT.1, PCA9685PW.28 (VDD), R1.2, R2.2, R4.2
5_B: PCA9685PW.21 (LED14), Q15.1 (G)
5_G: PCA9685PW.20 (LED13), Q14.1 (G)
5_R: PCA9685PW.19 (LED12), Q13.1 (G)
A0: AD0.2, PCA9685PW.1 (A0)
A1: AD1.2, PCA9685PW.2 (A1)
A2: AD2.2, PCA9685PW.3 (A2)
A3: AD3.2, PCA9685PW.4 (A3)
A4: AD4.2, PCA9685PW.5 (A4)
A5: AD5.2, PCA9685PW.24 (A5)
GND: AD0.3, AD1.3, AD2.3, AD3.3, AD4.3, AD5.3, C1.2, C2.2 (-), C3.2 (-), D1.C, D2.C, DATA_IN.2, DATA_OUT.2, LEDPWR.2, PCA9685PW.14 (GND), PCA9685PW.25 (EXTCLK), Q1.2 (S), Q2.2 (S), Q3.2 (S), Q4.2 (S), Q5.2 (S), Q6.2 (S), Q7.2 (S), Q8.2 (S), Q9.2 (S), Q10.2 (S), Q11.2 (S), Q12.2 (S), Q13.2 (S), Q14.2 (S), Q15.2 (S)
unnamed: D2.A, R3.1
unnamed: D1.A, R4.1
OE: DATA_IN.5, DATA_OUT.5, PCA9685PW.23 (/OE)
RGB1_B: JP3.4, Q3.3 (D)
RGB1_G: JP3.2, Q2.3 (D)
RGB1_R: JP3.3, Q1.3 (D)
RGB2_B: JP4.4, Q6.3 (D)
RGB2_G: JP4.2, Q5.3 (D)
RGB2_R: JP4.3, Q4.3 (D)
RGB3_B: JP5.4, Q9.3 (D)
RGB3_G: JP5.2, Q8.3 (D)
RGB3_R: JP5.3, Q7.3 (D)
RGB4_B: JP6.4, Q12.3 (D)
RGB4_G: JP6.2, Q11.3 (D)
RGB4_R: JP6.3, Q10.3 (D)
RGB5_B: JP7.4, Q15.3 (D)
RGB5_G: JP7.2, Q14.3 (D)
RGB5_R: JP7.3, Q13.3 (D)
SCL: DATA_IN.4, DATA_OUT.4, PCA9685PW.26 (SCL), R1.1
SDA: DATA_IN.3, DATA_OUT.3, PCA9685PW.27 (SDA), R2.1
VIN: C2.1 (+), JP3.1, JP4.1, JP5.1, JP6.1, JP7.1, LEDPWR.1, R3.2

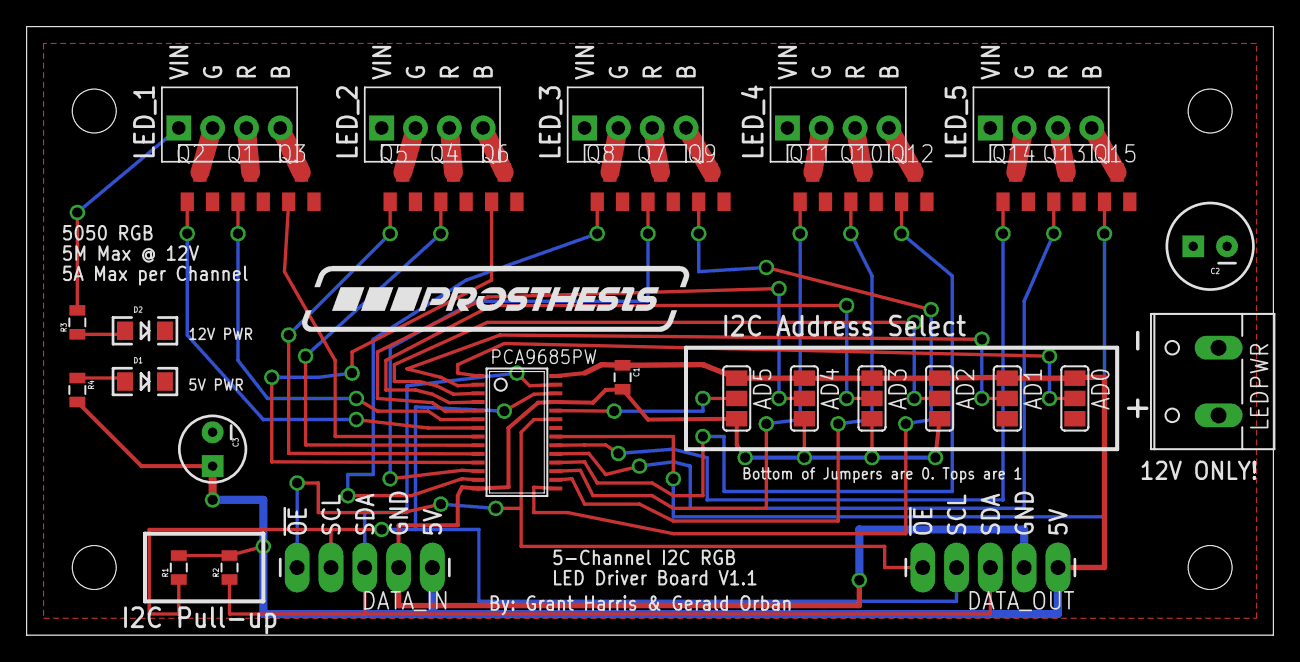
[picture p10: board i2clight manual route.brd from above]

Board: 2 copper layers, 93.7 x 45.7 mm, 44 parts (0 on the bottom side), 44 nets.

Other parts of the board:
U$2: PROSTHESIS

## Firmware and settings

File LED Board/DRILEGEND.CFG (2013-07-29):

InputUserCfg = 1
SymbolLayer = 144
SymbolSize = 40
SymbolWidth = 4
TextSize = 70.0000
TextRatio = 5
IdxFnt = 0
decMM = 2
decMIL = 0
SortHoles = 1
TolPlated = 0.02
TolNonPlated = 0.03
PlatedStatusNot = NOT
PlatedStatusBoth = BOTH
PlatedStatusYes = YES
VerticalChart = 1
HighCellFactor = 1.10
WideCellFactor = 1.10
CellOutline = 4
TitleOutline = 4
TableOutline = 8
SymbTitle = Sym
ToolTitle = N°
MMTitle = MM
MilTitle = Mils
MicTitle = Mic
QtyTitle = Qty
TypeTitle = Plated
ToleTitle = Tol
SymbRank = 1
ToolRank = 2
MMRank = 4
MilRank = 3
MicRank = 0
QtyRank = 5
TypeRank = 6
ToleRank = 0
OutputDrillRack = 0
DrillRackFile = DRILLRACK.DRL
Unit = 0
OutputUserCfg = 1
UserCfgFile = DRILEGEND.CFG

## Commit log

2013-07-29 Committing initial schematics
    [DRILEGEND.CFG, contact control board smd.brd, contact control board smd.sch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]
2013-07-30 Adding gitignore for backups and committing WIP files for motor shield.
    [Prosthesis Motor Shield.brd, Prosthesis Motor Shield.sch]
2013-07-30 Added additional HEX schmitt trigger inverters for debouncing.
    Also fixed pin configurations in the MEGA shield. Some were backards.
    Connected all of the pin headers to their respective components and
    added debouncing for all switch signals.
    [Prosthesis Motor Shield.brd, Prosthesis Motor Shield.sch]
2013-07-31 Incremental changes for layout.
    [Prosthesis Motor Shield.brd, Prosthesis Motor Shield.sch]
2013-07-31 Splitting M1 and M2 debouncing signals between the inverters
    [Prosthesis Motor Shield.brd, Prosthesis Motor Shield.sch]
2013-08-02 Adding capacitor charge state sense for CCB
    Theoretical part selection. Not for usage until testing!
    [contact control board.brd, contact control board.sch]
2013-08-02 Added inverter w/ schmitt trigger to the output of the opamp to fixup its outputs.
    [contact control board.brd, contact control board.sch]
2013-08-02 Replaced op-amp with voltage comparitor. Need to redo the voltage dividers for a 0-18V range or similar instead of 0-5V
    [contact control board.brd, contact control board.sch]
2013-08-02 Updating voltage dividers to common resistor values
    [contact control board.brd, contact control board.sch]
2013-08-02 Final draft design for CCB (thru-hole) before proto-boarding.
    Replaced SPST relay with DPDT relay so that its NC connections will
    drain the capacitors and its NO connections will charge them. This way
    we can wait a shorter period of time after powering down the machine
    before servicing!
    [contact control board.brd, contact control board.sch]
2013-08-02 Simplified board by removing power LED pin, it's just run from 5V now.
    Swapped pins in the voltage comparator to produce a HIGH output when the
    capacitor voltage drops below the reference voltage (instead of vice
    versa).
    [contact control board.brd, contact control board.sch]
2013-08-03 Updating layout to 2"x3". Need to make smaller!
    [contact control board.brd, contact control board.sch]
2013-08-04 Redoing voltage dividers so that they produce voltages on the oeprational range of our voltage comparator. Also re-wired the voltage
    monitor for the capacitors to use capacitor voltage and not the voltage
    over the pre-charge resistors.
    [contact control board.brd, contact control board.sch]
2013-08-04 Renamed some labels to be more descriptive in their usage.
    [contact control board.brd]
2013-08-06 Deleting SMD variant of the CCB for now.
    Keeping the two boards in design sync while iterating on one wasn't a
    smart idea. Conversion will happen once the CCB has been validated using
    proto-boards. Did a test route of the CCB using thru-hole parts in a
    2"x3" space and there's a ton of room. Cool!
    [contact control board smd.brd, contact control board smd.sch, contact control board.brd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]
2013-08-06 Fixing bad note in design
    [contact control board.sch]
2013-08-08 Added BMS interface board and updated CCB with current limiting resistor
    [BMS Interface.brd, BMS Interface.sch, contact control board.brd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]
2013-08-09 Updating layout for BMS interface PCB and removed 5V input as it was no longer necessary.
    [BMS Interface.brd, BMS Interface.sch]
2013-08-13 Opto-coupling precharge signal with op-amp output
    [contact control board.brd, contact control board.sch]
2013-08-13 Added buffer to use the output of the Op-Amp and split
    it between an indicator LED and a digital signal output. Tested and
    validated using breadboards
    [contact control board.brd, contact control board.sch]
2013-08-14 Using the proper chip package for the buffer chip
    [contact control board.brd, contact control board.sch]
2013-08-17 Updated precharge design
    Replaced transistor with a FET as the Arduino can't source enough
    current to trigger both the relay and the LED... At least not with the
    transistors which were specced.
    [contact control board.brd, contact control board.sch]
2013-08-18 Mostly routed. Replaced all thru-hole with SMD components. Much smaller!
    [contact control board.brd, contact control board.sch]
2013-08-18 Fixed values for FETs and some resistors whcih were cut and paste errors.
    [contact control board.brd, contact control board.sch]
2013-08-20 Routed CCB using SMD components. Ready to manufacture!
    [BMS Interface.brd, contact control board.brd]
2013-08-21 Fixed wiring of capacitor charge sensing which caused ground planes to need re-routing
    [contact control board.brd, contact control board.sch]
2013-09-08 Finally found part # for fuse holder!
    [BMS Interface.brd, contact control board.brd, contact control board.sch]
2013-09-08 Routed motor controller arduino shield. Challenging!
    [Prosthesis Motor Shield.brd, Prosthesis Motor Shield.sch]
2013-09-15 Re-routed motor shield with new molex connectors.
    Still may want to put the CCB headers as a better connector, too. Need
    to source a good 8x2 pin header first. Added prosthesis logo to motor
    board. Added sensor shield schematic (copy of motor board to start)
    [Prosthesis Motor Shield.brd, Prosthesis Sensor Shield.brd, Prosthesis Sensor Shield.sch]
2013-09-15 Moved MCB titles to places layer from names
    Cleared sensor shield of all components
    [Prosthesis Motor Shield.brd, Prosthesis Sensor Shield.brd, Prosthesis Sensor Shield.sch]
2013-09-22 CHanged all connectors on MCB to use Molex
    Changed most of the connectors on the BMS interface to use molex as
    well.
    [BMS Interface.brd, BMS Interface.sch, Prosthesis Motor Shield.brd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]
2013-09-22 Missed a save before last commit.
    [Prosthesis Motor Shield.brd]
2013-09-22 Fixed wire routing on CCB. Added polarity to BMS
    output.
    [BMS Interface.brd, contact control board.brd, contact control board.sch]
2013-09-23 Moved BMS interface to use an ATX connector.
    [BMS Interface.brd, BMS Interface.sch]
2013-09-24 Routed BMS interface board and added branding.
    Changed branding for CCB and MCBs
    [BMS Interface.brd, Prosthesis Motor Shield.brd, contact control board.brd]
2013-10-08 Added PMS board schematic.
    [BMS Interface.brd, pms.brd, pms.sch]
2013-10-12 UPdating resistor packages to sizes which are
    capable of disappating the appropriate amount of power.
    [BMS Interface.brd, BMS Interface.sch, Prosthesis Motor Shield.brd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]
2013-10-13 Added capacitors for the three main boards
    [BMS Interface.brd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]

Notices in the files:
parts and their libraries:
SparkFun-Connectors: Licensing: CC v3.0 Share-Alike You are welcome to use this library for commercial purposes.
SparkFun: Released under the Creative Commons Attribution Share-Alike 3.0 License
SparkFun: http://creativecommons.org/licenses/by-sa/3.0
